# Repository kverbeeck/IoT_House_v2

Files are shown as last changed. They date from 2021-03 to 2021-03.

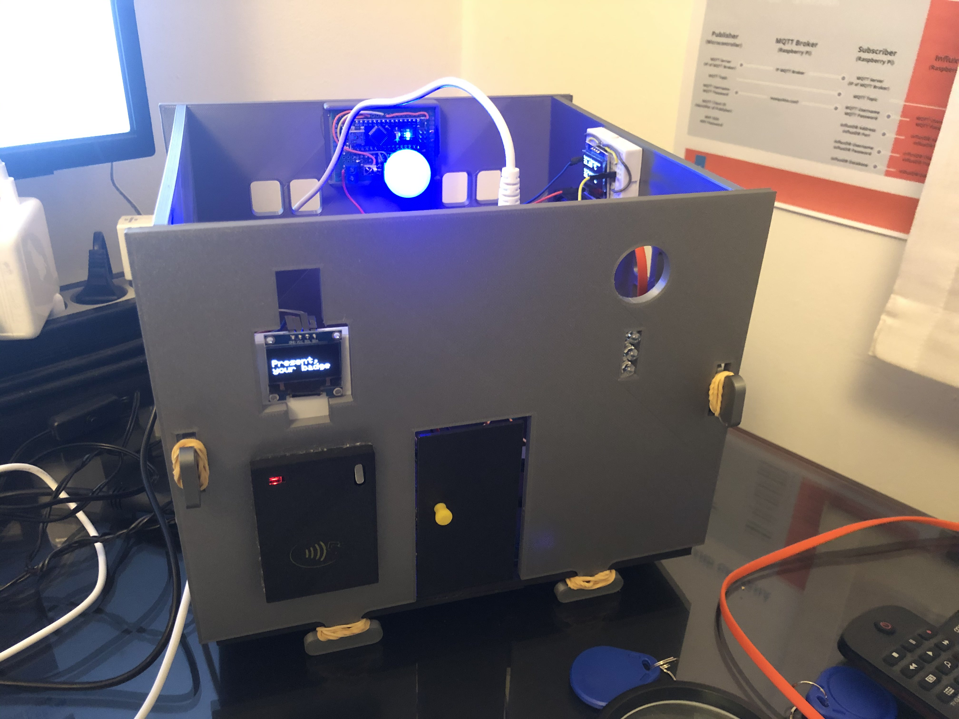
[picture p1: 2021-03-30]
Photos/IMG_9261.jpg

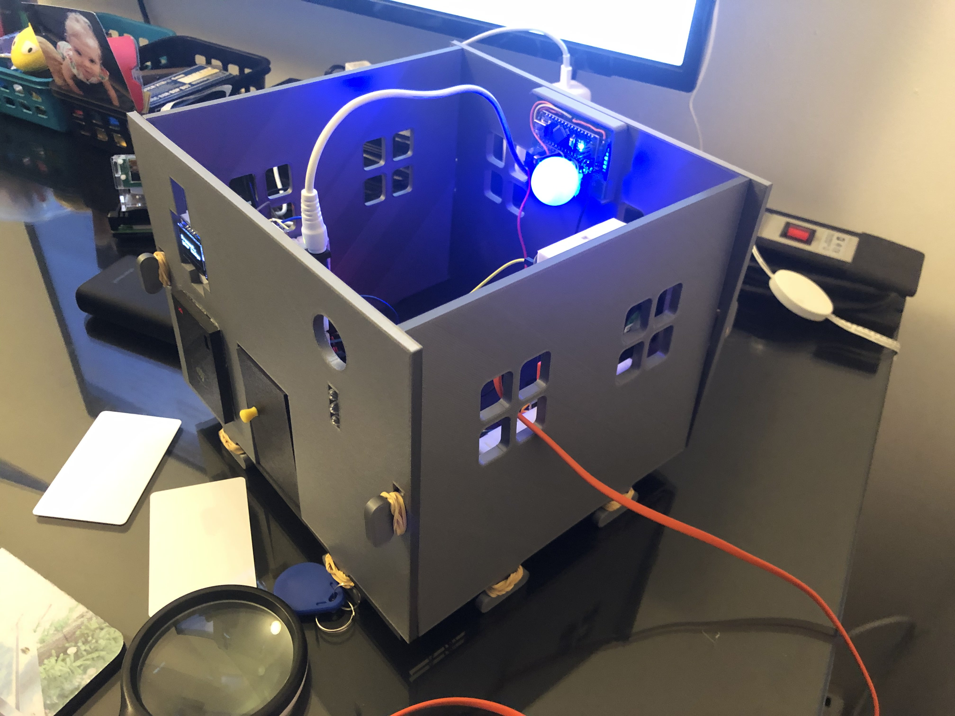
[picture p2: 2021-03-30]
Photos/IMG_9271.jpg

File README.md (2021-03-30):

# FreestyleIoT_Project

For this project, i ve chosen to upgrade my existing IoT house >> https://www.youtube.com/watch?v=xoJDLW5kjLk and make it really internet of things by monitoring sensor outputs locally and via the BLYNK app >> https://blynk.io/ and control actuators locally and via BLYNK.

Link to the kitlist >> https://docs.google.com/spreadsheets/d/1GlvLmVtN7IZRM3OurWxvNwD4gjMKiJFMoon5G-sc7mI/edit?usp=sharing
Link to the demo video of this project >> https://www.youtube.com/watch?v=XRs4ygz1CqU
Link to my PrusaPrinters page for 3D Printing files and instructions. https://www.prusaprinters.org/prints/61861-iot-hous-version-1

The full Schematic can be found in this repository.

Read the extra notes in the ESP32 codes for additional information about what the line of code does.

If you have a 3D printer and want to print your own house, you can find the STL files in this repository.
The STL files are still the IoT house version 1, i will update these files in the near future to have a cleaner finish.

i recommend a 0.2 layer height for the bigger parts and 0.1 for the smaller detail, no rafts, skirts, supports needed.

All ESP32 code i wrote for this project can be found in this repository as well.

Steps
_____________________________

1) Start by building the project following the schematics, You can also have a look at the Photos and screenshots (BLYNK app) 
in this repository and the demonstration video >> https://www.youtube.com/watch?v=XRs4ygz1CqU
2) Follow the instructions to set up BLYNK here >> https://blynk.io/en/getting-started , however i recommend setting up your own BLYNK server on a Raspberry Pi 4B, when using the CLOUD based server, there are limitations on how many widgets you will be able to use. Follow these instructions >> https://github.com/blynkkk/blynk-server
3) Open you Arduino IDE >> https://www.arduino.cc/en/software and first install the necessary board managers (ESP32) if not yet installed, follow the instructions on this page if Windows >> https://randomnerdtutorials.com/installing-the-esp32-board-in-arduino-ide-windows-instructions/  and this page if MacOS or Linux  https://randomnerdtutorials.com/installing-the-esp32-board-in-arduino-ide-mac-and-linux-instructions/
4) Install following libraries from following links. In github, click on the Green "Code" button and then "Download zip". No need to unzip the file
You can then install these like follows >> In Arduino IDE, go to Sketch > Include Library > Add . ZIP library and select the library you’ve just downloaded.
I recommend to fully restart Arduino IDE after installing all libraries !!!

Wire.h >> https://github.com/espressif/arduino-esp32 (This is a package af several neede libraries)
Adafruit_Sensor.h >> https://github.com/adafruit/Adafruit_Sensor
Adafruit_BME280.h >> https://github.com/adafruit/Adafruit_BME280_Library
WiFi.h >> https://github.com/espressif/arduino-esp32 (This is a package af several neede libraries)
WiFiClient.h >> https://github.com/espressif/arduino-esp32 (This is a package af several neede libraries)
BlynkSimpleEsp32.h >> https://github.com/blynkkk/blynk-library
Adafruit_SSD1306.h >> https://github.com/adafruit/Adafruit_SSD1306
Fonts/FreeSerif9pt7b.h >> https://learn.adafruit.com/adafruit-gfx-graphics-library/using-fonts
Adafruit_GFX.h >> https://github.com/adafruit/Adafruit-GFX-Library
Servo.h >> https://github.com/RoboticsBrno/ServoESP32
MFRC522.h >> https://github.com/miguelbalboa/rfid/archive/master.zip
SPI.h >> https://github.com/PaulStoffregen/SPI

5) Create your project in the BLYNK app. Because we use 2 x ESP32 for 1 project, we will need 2 Tokens to be generated by the app. Again, see the instructions on these sites for set this up >> https://blynk.io/en/getting-started and >> https://github.com/blynkkk/blynk-server when using your own local server.
6) Set up the BLYNK project on your Android or iPhone as follows, See BLYNK Screenshots folder in this repository.
7) In Arduino IDE, go to File >> Examples >> MFRC522 >> DumpInfo. This will open a sketch that will read your RFID Card(s) UID(s), write these down, you will need this info later. Upload this sketch to the ESP32 that has the MFRC522 RFID Card Reader/Writer connected to it.
8) Change following lines in "IoT_House_ESP32_BLYNK_ACCESS_CONTROL.ino" to get connected to your Wi-Fi access point, the correct BLYNK server and Token and program the right RFID UIDs for access to the House >>

// Own Blynk Server and port
char server[] = "BLYNK Server IP address"; // RPi4B    <<<<<
#define port 8080 // Default port

// You should get Auth Token in the Blynk App.
// Go to the Project Settings (nut icon).
char auth[] = "Put your BLYNK Token here";    <<<<<

/*
   Wi-Fi
*/
// Your WiFi credentials.
// Set password to "" for open networks.
char ssid[] = "Your SSID"; // Use your modems Wi-Fi    <<<<<
char pass[] = "Your Wi-Fi password";    <<<<<

if ((content.substring(1) == "C9 D1 82 A2") || (content.substring(1) == "47 E6 19 B2")) // Zet hier de UID(s) van de kaarten die je toegang wil verschaffen     <<<<<
    // In case of blue badge UID: C9 D1 82 A2 or blue badge UID: 47 E6 19 B2
  {
    Serial.println("\t >>> Your RFID tag is known");

    if (content.substring(1) == "C9 D1 82 A2") {    <<<<<
      // Blij gezicht + blije toon + bericht op Serial Monitor !!!
      Serial.print("You may enter, welcome Koen !!!");
      Serial.println();
      Blynk.notify("Koen has just entered the IoT House");
      welcome_OLED_Koen();
    }
    if (content.substring(1) == "47 E6 19 B2") {    <<<<<
      // Blij gezicht + blije toon + bericht op Serial Monitor !!!
      Serial.print("You may enter, welcome Vero !!!");
      Serial.println();
      Blynk.notify("Vero has just entered the IoT House");
      welcome_OLED_Vero();
    }

9) Change following lines in "IoT_House_ESP32_CENTRAL_HEATER_GAS_Detection_FINAL.ino" to get connected to your Wi-Fi access point, the correct BLYNK server and Token. >>

// Own Blynk Server and port
char server[] = "BLYNK Server IP address"; // RPi4B    <<<<<
#define port 8080 // Default port

// You should get Auth Token in the Blynk App.
// Go to the Project Settings (nut icon).
char auth[] = "Put your BLYNK Token here";    <<<<<

/*
   Wi-Fi
*/
// Your WiFi credentials.
// Set password to "" for open networks.
char ssid[] = "Your SSID"; // Use your modems Wi-Fi    <<<<<
char pass[] = "Your Wi-Fi password";    <<<<<

10) Now its time to upload the codes to the ESP32s. Upload "IoT_House_ESP32_BLYNK_ACCESS_CONTROL.ino" to the first ESP32 and "IoT_House_ESP32_CENTRAL_HEATER_GAS_Detection_FINAL.ino" to the second one. See this video for uploading code to the ESP32 using Arduino IDE, make sure that the needed drivers are installed for your COM port >> https://www.youtube.com/watch?v=G6l259vEt7k and https://www.youtube.com/watch?v=0XX6fwdxO9Q

11) If your wirring is correct, both codes got uploaded to the ESP32s without errors and your BLYNK got set-up correctly, it should operate like shown in the demo video.

Enjoy

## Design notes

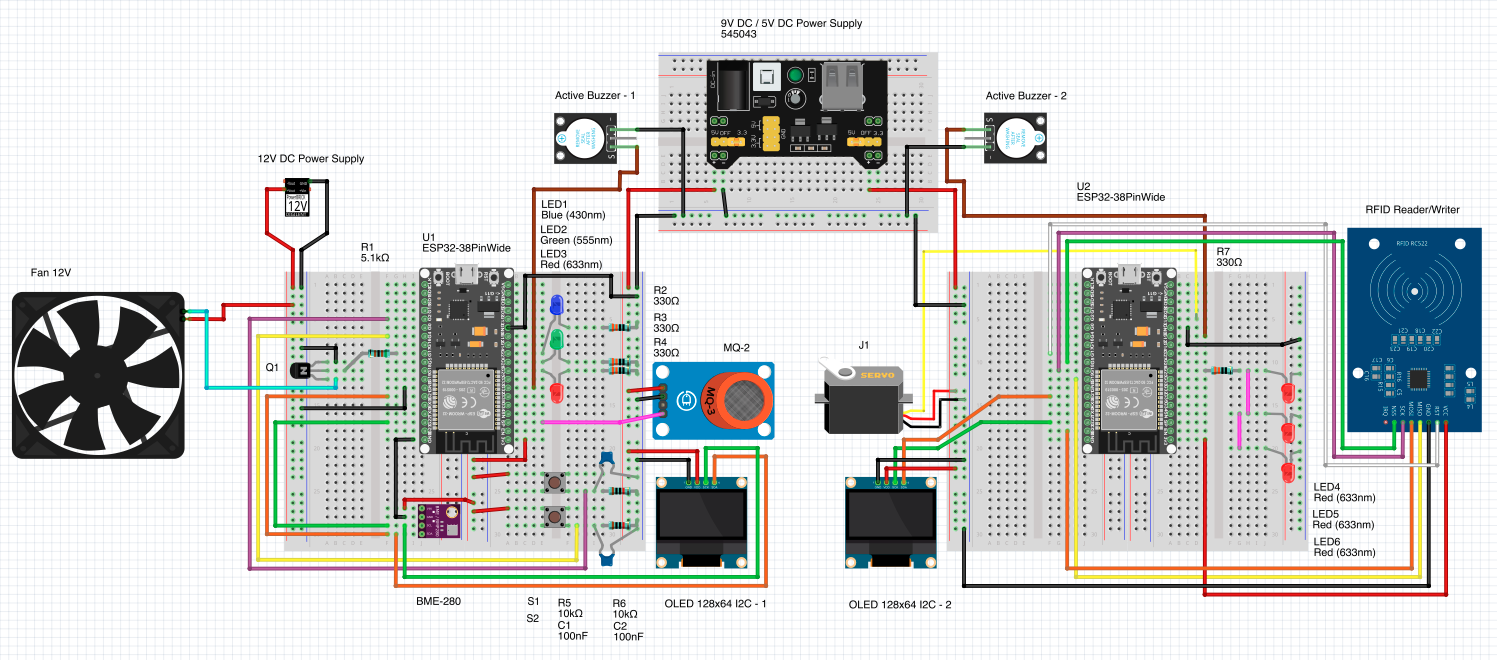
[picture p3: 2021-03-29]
Schematics/Breadboard.png

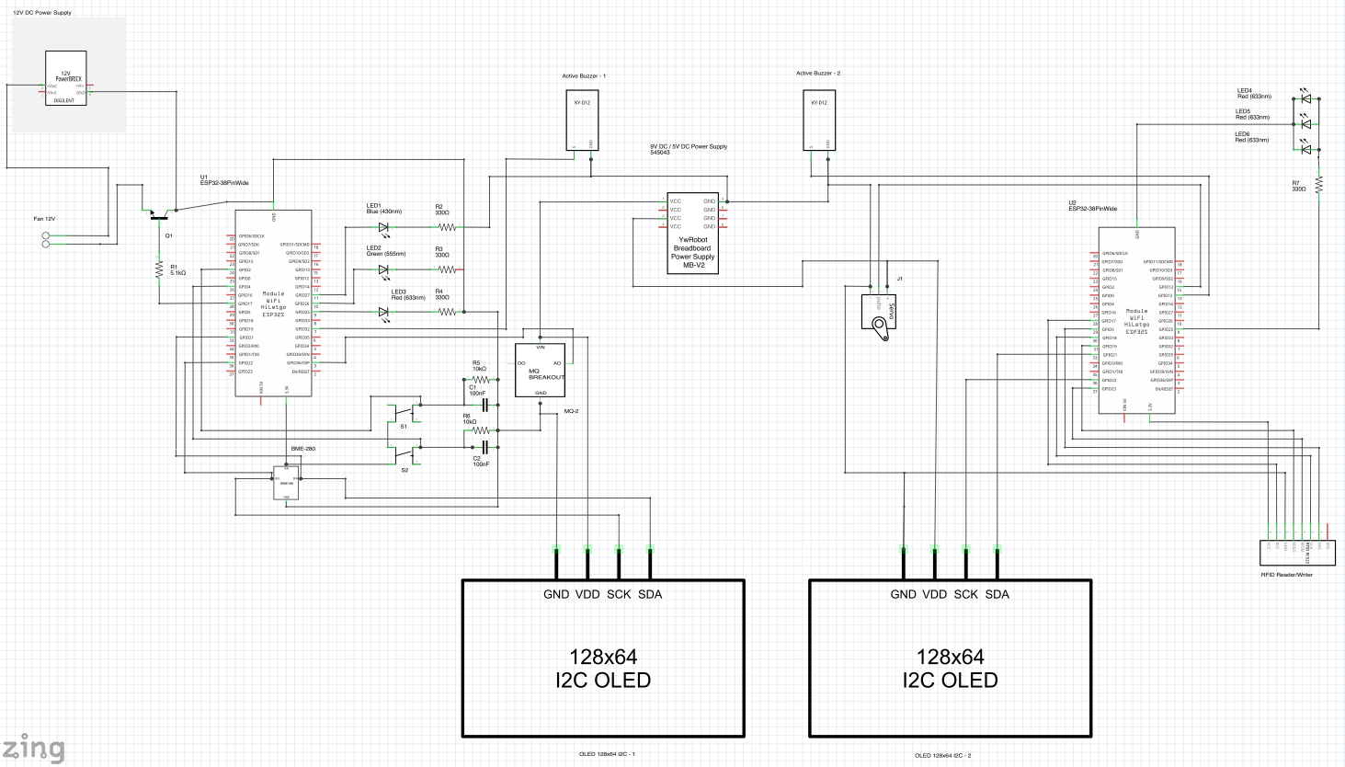
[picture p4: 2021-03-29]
Schematics/Schematics.png

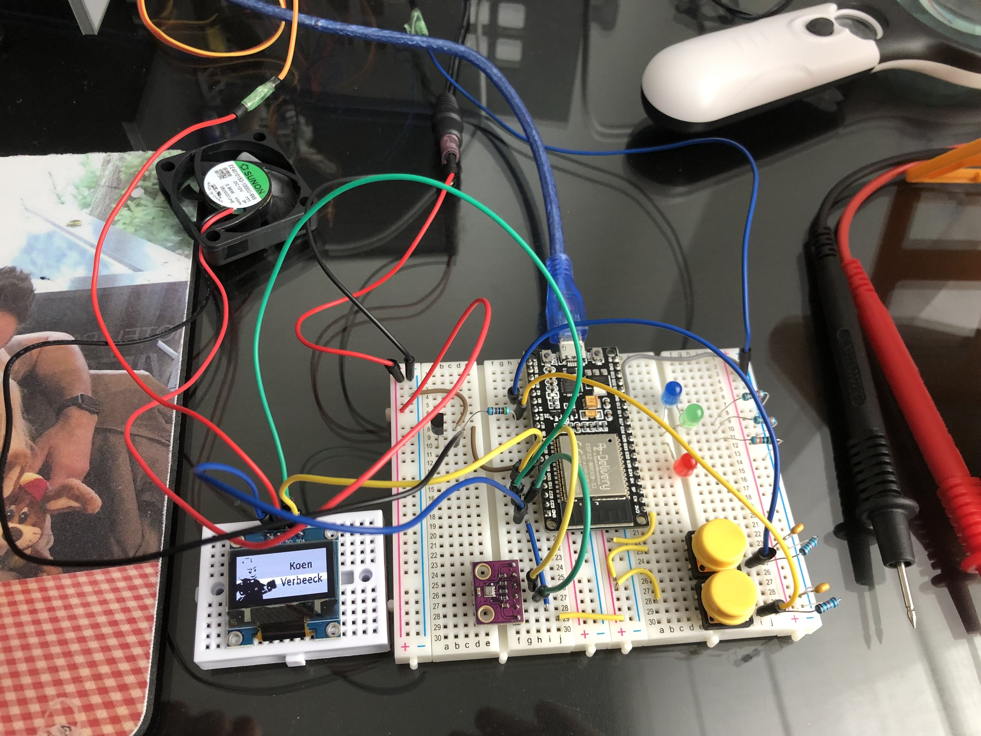
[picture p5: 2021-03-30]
Photos/Thermostat.jpg

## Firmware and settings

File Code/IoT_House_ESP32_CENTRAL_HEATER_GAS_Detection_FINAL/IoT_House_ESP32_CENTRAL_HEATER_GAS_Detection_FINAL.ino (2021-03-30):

/*
 * Final Project Sensors and Interfacing
   Koen Verbeeck
   
   Freestyle IoT project: Central Heater + GAS Detection
*/

#define BLYNK_PRINT Serial

#include <Wire.h> // Library for I2C Communication
#include <Adafruit_Sensor.h> // Unified Adafruit Sensor abstraction layer Library
#include <Adafruit_BME280.h> // Library for BME280 Sensor
#include <WiFi.h>
#include <WiFiClient.h>
#include <BlynkSimpleEsp32.h> // Library for BLYNK
#include <Adafruit_SSD1306.h> // Library for OLED
#include <Fonts/FreeSerif9pt7b.h> // Library for Fonts / OLED

// OLED 128x64 Screen
#define SCREEN_WIDTH 128 // OLED display width, in pixels
#define SCREEN_HEIGHT 64 // OLED display height, in pixels

// Initialize the OLED screen
Adafruit_SSD1306 display(SCREEN_WIDTH, SCREEN_HEIGHT, &Wire, -1);

// BITMAP Koen_LEGO start-up screen
static const uint8_t image_data_KoenLego2[1024] = {
  0xff, 0xff, 0xff, 0xff, 0xff, 0xff, 0xff, 0xff, 0xff, 0xff, 0xff, 0xff, 0xff, 0xff, 0xff, 0xff,
  0xff, 0xff, 0xff, 0xff, 0xff, 0xff, 0xff, 0xff, 0xff, 0xff, 0xff, 0xff, 0xff, 0xff, 0xff, 0xff,
  0xff, 0xff, 0xff, 0xff, 0xff, 0xff, 0xff, 0xff, 0xff, 0xff, 0xff, 0xff, 0xff, 0xff, 0xff, 0xff,
  0xff, 0xf0, 0x3f, 0xff, 0xff, 0xff, 0xff, 0xff, 0xff, 0xff, 0xff, 0xff, 0xff, 0xff, 0xff, 0xff,
  0xff, 0xff, 0xf7, 0xff, 0xff, 0xff, 0xff, 0xff, 0xff, 0xff, 0xff, 0xff, 0xff, 0xff, 0xff, 0xff,
  0xff, 0xff, 0xf7, 0xff, 0xff, 0xff, 0xff, 0xff, 0xff, 0xff, 0xff, 0xff, 0xff, 0xff, 0xff, 0xff,
  0xff, 0xff, 0xf7, 0xff, 0xff, 0xff, 0xff, 0xff, 0xff, 0xff, 0xff, 0xff, 0xff, 0xff, 0xff, 0xff,
  0xff, 0xbf, 0xf7, 0xff, 0xff, 0xff, 0xff, 0xff, 0xff, 0xff, 0xff, 0xff, 0xff, 0xff, 0xff, 0xff,
  0xff, 0x3f, 0xf3, 0xff, 0xff, 0xff, 0xff, 0xff, 0xff, 0xff, 0xff, 0xff, 0xff, 0xff, 0xff, 0xff,
  0xff, 0x3f, 0xf7, 0xff, 0xff, 0xff, 0xff, 0xff, 0xff, 0xff, 0xff, 0xff, 0xff, 0xff, 0xff, 0xff,
  0xff, 0xff, 0xff, 0xff, 0xff, 0xff, 0xff, 0xff, 0xff, 0xff, 0xff, 0xff, 0xff, 0xff, 0xff, 0xff,
  0xff, 0xff, 0xff, 0xff, 0xff, 0xff, 0xff, 0xff, 0xff, 0xff, 0xff, 0xff, 0xff, 0xff, 0xff, 0xff,
  0xff, 0xff, 0xff, 0xff, 0xff, 0xff, 0xff, 0xff, 0xff, 0xff, 0xff, 0xff, 0xff, 0xff, 0xff, 0xff,
  0xff, 0xff, 0xff, 0xff, 0xff, 0xff, 0xff, 0xff, 0xff, 0xff, 0xff, 0xff, 0xff, 0xff, 0xff, 0xff,
  0xff, 0xff, 0xff, 0xff, 0xff, 0xff, 0xff, 0xff, 0xff, 0xff, 0xff, 0xff, 0xff, 0xff, 0xff, 0xff,
  0xff, 0xff, 0xff, 0xff, 0xff, 0xff, 0xff, 0xff, 0xff, 0xff, 0xff, 0xff, 0xff, 0xff, 0xff, 0xff,
  0xff, 0xff, 0xff, 0xef, 0xff, 0xff, 0xff, 0xff, 0xff, 0xf3, 0x9f, 0xff, 0xff, 0xff, 0xff, 0xff,
  0xff, 0xff, 0xff, 0x9f, 0xff, 0xff, 0xff, 0xff, 0xff, 0xf3, 0x1f, 0xff, 0xff, 0xff, 0xff, 0xff,
  0xff, 0xff, 0xff, 0x3f, 0xff, 0xff, 0xff, 0xff, 0xff, 0xf3, 0x3e, 0x7e, 0x7b, 0x3f, 0xff, 0xff,
  0xff, 0xfe, 0x03, 0x7f, 0xff, 0xff, 0xff, 0xff, 0xff, 0xf2, 0x78, 0x18, 0x38, 0x1f, 0xff, 0xff,
  0xff, 0xff, 0xf3, 0xdf, 0xff, 0xff, 0xff, 0xff, 0xff, 0xf0, 0x71, 0x99, 0x98, 0x9f, 0xff, 0xff,
  0xff, 0xff, 0xff, 0x8f, 0xff, 0xff, 0xff, 0xff, 0xff, 0xf0, 0x73, 0x99, 0x99, 0x9f, 0xff, 0xff,
  0xff, 0xff, 0xd7, 0x9f, 0xff, 0xff, 0xff, 0xff, 0xff, 0xf2, 0x73, 0x90, 0x19, 0x9f, 0xff, 0xff,
  0xff, 0xff, 0x97, 0x9f, 0xff, 0xff, 0xff, 0xff, 0xff, 0xf3, 0x33, 0x91, 0xf9, 0x9f, 0xff, 0xff,
  0xff, 0xff, 0x87, 0xff, 0xff, 0xff, 0xff, 0xff, 0xff, 0xf3, 0x13, 0x99, 0xf9, 0x9f, 0xff, 0xff,
  0xff, 0xff, 0xc7, 0xff, 0xff, 0xff, 0xff, 0xff, 0xff, 0xf3, 0x98, 0x18, 0x19, 0x9f, 0xff, 0xff,
  0xff, 0xff, 0xff, 0xff, 0xff, 0xff, 0xff, 0xff, 0xff, 0xf3, 0x88, 0x3c, 0x19, 0x9f, 0xff, 0xff,
  0xff, 0xff, 0xff, 0xff, 0xff, 0xff, 0xff, 0xff, 0xff, 0xff, 0xff, 0xff, 0xff, 0xff, 0xff, 0xff,
  0xff, 0xff, 0xff, 0xdf, 0xff, 0xff, 0xff, 0xff, 0xff, 0xff, 0xff, 0xff, 0xff, 0xff, 0xff, 0xff,
  0xff, 0xff, 0xff, 0xbf, 0xff, 0xff, 0xff, 0xff, 0xff, 0xff, 0xff, 0xff, 0xff, 0xff, 0xff, 0xff,
  0xef, 0xff, 0xf0, 0x3f, 0xff, 0xff, 0xff, 0xff, 0xff, 0xff, 0xff, 0xff, 0xff, 0xff, 0xff, 0xff,
  0xff, 0xff, 0xf8, 0xef, 0xff, 0xff, 0xff, 0xff, 0xff, 0xff, 0xff, 0xff, 0xff, 0xff, 0xff, 0xff,
  0xf7, 0xc1, 0xff, 0xcf, 0xff, 0xff, 0xff, 0xff, 0xff, 0xff, 0xff, 0xff, 0xff, 0xff, 0xff, 0xff,
  0xf8, 0x00, 0x1f, 0x1f, 0xff, 0xff, 0xff, 0xff, 0xff, 0xff, 0xff, 0xff, 0xff, 0xff, 0xff, 0xff,
  0xfc, 0x00, 0x00, 0x3f, 0xff, 0xff, 0xff, 0xff, 0xff, 0xff, 0xff, 0xff, 0xff, 0xff, 0xff, 0xff,
  0xfe, 0x00, 0x00, 0x07, 0xff, 0xff, 0xff, 0xff, 0xff, 0xff, 0xff, 0xff, 0xff, 0xff, 0xff, 0xff,
  0xff, 0x00, 0x07, 0x01, 0xff, 0xff, 0xff, 0xff, 0xff, 0xff, 0xfb, 0xff, 0xff, 0xff, 0xe7, 0xff,
  0xf0, 0x00, 0x8e, 0x00, 0xff, 0xff, 0xff, 0xfc, 0xf9, 0xff, 0xf9, 0xff, 0xff, 0xff, 0xe7, 0xff,
  0x80, 0x00, 0x00, 0x00, 0x7f, 0xff, 0xc3, 0xfc, 0xf9, 0xff, 0xf9, 0xff, 0xff, 0xff, 0xe7, 0xff,
  0x03, 0x00, 0x00, 0x00, 0x7f, 0xfe, 0x03, 0xfe, 0x73, 0xff, 0xfb, 0xff, 0xff, 0xff, 0xe7, 0xff,
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
};

// Push buttons
#define up_Button 2 // Controls the temp in the upward direction
#define down_Button 4 // Controls the temp in the downward direction
int upVal; // Status of Up-Button
int downVal; // Status of Down-Button
String msg = "Down-button state is ";
String msg2 = "  Up-Button state is: ";
int dt = 100; // Delay time, only when pressing a button

// Configure start-up temp
float setTemp = 20.00;

// Define LEDs
#define blue_LED 27
#define green_LED 26
#define red_LED 25

// Define Fan
#define fan 17

// Define MQ-2 Gas Detector
#define GasDetector 36
// MQ-2 GasSensor threshold value for alarm, value between 0 and 4095 (12bits)
// value will easely pass this threshold if gas is detected.
int sensorTresh = 2000;
// To avoid that BLYNK will send a notification every 5 seconds (default)
unsigned long old_millis = 0;
int no_Alarm = 60000; // 60 seconds

// Define Active Buzzer
#define buzzer 32

// Own Blynk Server and port
char server[] = "192.168.10.122"; // RPi4B
#define port 8080 // Default port

// You should get Auth Token in the Blynk App.
// Go to the Project Settings (nut icon).
char auth[] = "********";

// Your WiFi credentials.
// Set password to "" for open networks.
char ssid[] = "********"; // Use your own modems' Wi-Fi
char pass[] = "********";

// Create an object "bme" for I2C communication
Adafruit_BME280 bme;

// Functions to read and store temperature, pressure, altitude and humidity
// This code is telling the ESP32 that every time Blynk app sends a _READ request on a Virtual Pin,
// the ESP32 will read the sensor on that Virtual Pin and then write the sensor reading back to Blynk app.

BLYNK_READ(V1) // on Virtual Pin 1
{
  // Read temperature minus correction
  float temperature = (bme.readTemperature()) - 4.0;
  Blynk.virtualWrite(V1, temperature); // Send to Blynk
}

// This function will be called every time Temp. Slider Widget
// in Blynk app writes values to the Virtual Pin V2
BLYNK_WRITE(V2)
{
  // assigning incoming value from pin V2 to a float variable
  setTemp = param.asFloat();;
  // process received value
}

// Virtueele LEDs in BLYNK
WidgetLED vRedLED(V3); //virtual pin 3
WidgetLED vGreenLED(V4); //virtual pin 4
WidgetLED vBlueLED(V5); //virtual pin 5

BLYNK_READ(V6) // on Virtual Pin 6
{
  // Read the MQ-2 Sensor value
  int gasValBLYNK = analogRead(GasDetector);
  Blynk.virtualWrite(V6, gasValBLYNK); // Send to Blynk
}

void setup() {

  // Start the Serial Monitor @ 115200 Baud rate
  Serial.begin(115200);
  delay(10);

  // Set the push-buttons as INPUT (Pull-UP in hardware)
  pinMode(up_Button, INPUT);
  pinMode(down_Button, INPUT);

  // Set LEDs as OUTPUT
  pinMode(blue_LED, OUTPUT);
  pinMode(green_LED, OUTPUT);
  pinMode(red_LED, OUTPUT);
  
  // Set Fan as OUTPUT
  pinMode(fan, OUTPUT);

  // Set MQ-2 Gas Detector as INPUT
  pinMode(GasDetector, INPUT);

  // Set buzzer as OUTPUT
  pinMode(buzzer, OUTPUT);

  // Because the OLED and the BME280 have different addresses, 
  // we can use the same I2C SDA and SCL lines without any problem.
  // The OLED display address is 0x3C and the BME280 address is 0x76.
  if (!display.begin(SSD1306_SWITCHCAPVCC, 0x3C)) {
    Serial.println(F("SSD1306 allocation failed"));
    for (;;);
  }
  delay(2000); // Pause for 2 seconds

  // Clear the buffer.
  display.clearDisplay();

  // Draw Start-up screen bitmap on the screen
  // const tImage KoenLego2 = { image_data_KoenLego2, 128, 64, 8 }; >> info from bitmap (LCD Image Converter)
  display.drawBitmap(0, 0, image_data_KoenLego2, 128, 64, 1);
  display.display();

  // Connect to Wi-Fi
  Serial.print("Connecting to ");
  Serial.println(ssid);
  WiFi.begin(ssid, pass);
  int wifi_ctr = 0;
  while (WiFi.status() != WL_CONNECTED) {
    delay(500);
    Serial.print(".");
  }
  Serial.println("WiFi connected");

  // Initialize the BLYNK Client
  Blynk.begin(auth, ssid, pass, server, port);

  // We initialize the BME280 sensor with the default 0x76 address.
  bool status = bme.begin(0x76);
  if (!status) {
    Serial.println("Could not find a valid BME280 sensor, check wiring!");
    while (1);
  }
}

void loop() {

  upVal = digitalRead(up_Button);
  downVal = digitalRead(down_Button);
  // Serial.print(msg + downVal);
  // Serial.println(msg2 + upVal);

  if (upVal == 1 && downVal == 0) { // When pressing the Up-Button
    setTemp += 0.50;
    delay(dt); // Delay time, only when pressing the button
    if (setTemp > 30.00) {
      setTemp = 30;
    }
  }
  if (upVal == 0 && downVal == 1) { // When pressing the Down-Button
    setTemp -= 0.50;
    delay(dt); // Delay time, only when pressing the button
    if (setTemp < 0.00) {
      setTemp = 0.00;
    }
  }

  // Control hardware LED and BLYNK Virtual LED
  // Central Heating will turn on if setTemp is lower than actual temp.
  // Cooler will turn on if setTemp is higher than actual temp.
  // Measured temp may differ 0,5°C from "setTemp"
  // Read temperature minus temperature correction & +/- 0.5°C
  float temp_high = bme.readTemperature() - 4.0 + 0.5;
  float temp_low = bme.readTemperature() - 4.0 - 0.5;

  
  // Heater On
  if (setTemp > temp_high) {
    digitalWrite(red_LED, HIGH), digitalWrite(green_LED, LOW), digitalWrite(blue_LED, LOW);
    vRedLED.on(), vGreenLED.off(), vBlueLED.off();
    digitalWrite(fan, LOW);
  }
  // Goldilocks Zone
  if ((setTemp > temp_low && setTemp < temp_high) || (setTemp == temp_low) || (setTemp == temp_high)) {
    digitalWrite(red_LED, LOW), digitalWrite(green_LED, HIGH), digitalWrite(blue_LED, LOW);
    vRedLED.off(), vGreenLED.on(), vBlueLED.off();
    digitalWrite(fan, LOW);
  }
  // Cooler On
  if (setTemp < temp_low) {
    digitalWrite(red_LED, LOW), digitalWrite(green_LED, LOW), digitalWrite(blue_LED, HIGH);
    vRedLED.off(), vGreenLED.off(), vBlueLED.on();
    digitalWrite(fan, HIGH);
  }

  // Read the MQ-2 Sensor value
  int gasVal = analogRead(GasDetector);
  // Serial.print("MQ-2 Sensor value: ");
  // Serial.println(gasVal);
  // Check if the MQ-2 sensor threshold value was reached.

  unsigned long new_millis = millis();
  
  if (gasVal >= sensorTresh){
    Serial.println(" >> threshold exeeded");
    digitalWrite(buzzer, HIGH);
    // Only send a BLYNK notification if more then 60 seconds have passed
    // since last notification
    if ((new_millis - old_millis) > no_Alarm) {
      Blynk.notify("GAS DETECTED !!!!!!!");
      old_millis = new_millis;
    }
  }
  else{
    // Serial.println(" >> below treshold"); 
    digitalWrite(buzzer, LOW);
  }
  

  // Clear the OLED buffer
  display.clearDisplay();
  // Set the text color to white, 
  // failing to set this wil give you a black screen
  display.setTextColor(WHITE);
  display.invertDisplay(false);
  // display current temperature in °C
  display.setFont();
  display.setTextSize(1);
  display.setCursor(0, 0);
  display.print("Current Temperature:");
  display.setTextSize(2);
  display.setCursor(0, 10);
  // Read temperature minus correction
  display.print(String((bme.readTemperature()) - 4.0));
  display.print(" ");
  display.setTextSize(1);
  display.cp437(true);
  display.write(167);
  display.setTextSize(2);
  display.print("C");
  // display set temperature in °C
  display.setTextSize(1);
  display.setCursor(0, 40);
  display.print("Set Temperature:");
  display.setTextSize(2);
  display.setCursor(0, 50);
  display.print(setTemp);
  display.print(" ");
  display.setTextSize(1);
  display.cp437(true);
  display.write(167);
  display.setTextSize(2);
  display.print("C");

  // "display.display()" is NOT necessary after every single drawing command,
  // you can batch up a bunch of drawing operations and then update the screen
  // all at once by calling "display.display()".
  display.display();

  // Run the Function to read and print temperature, pressure, altitude and humidity
  Blynk.run();
}
